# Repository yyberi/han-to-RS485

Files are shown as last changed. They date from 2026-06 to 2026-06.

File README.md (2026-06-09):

# Aidon HAN to RS485 Adapter

A small PCB that reads data from the Aidon electricity meter's HAN port and converts it to an RS485 bus, enabling integration with home automation systems, data loggers, and industrial equipment.

**PCB size:** 45 × 25 mm, 4-layer  
**Designed:** November 2022 by Yyberi

---

## Background

Aidon smart electricity meters (used by many Nordic utilities) expose a **HAN port** — a standard RJ12 connector that outputs UART serial data (DLMS/COSEM P1 telegrams) at 115200 baud. This board taps into that port and re-transmits the data over RS485, which is suited for longer cable runs and multi-drop topologies.

---

## How It Works

```
Aidon meter
  HAN port (RJ12)
       │
       ├─ +5V ──────────────────── powers the board
       └─ TX (UART 115200 baud) ── NPN buffer (Q1) ──► MAX13487E ──► RS485 (A/B)
```

1. The meter provides 5 V on the HAN port — no external power supply needed.
2. The UART TX line from the meter is buffered through an NPN transistor (Q1) that also handles the logic-level inversion.
3. The MAX13487EESA+T RS485 transceiver with automatic direction control retransmits the data on the RS485 bus.
4. TVS diode (D3) protects the RS485 lines against ESD and transients.
5. Two LEDs indicate power (D2) and data transmission activity (D1).

---

## Connectors

| Ref | Connector | Function |
|-----|---|---|
| J1  | RJ12 (DS1133-S60BPX) | HAN port — plugs into meter |
| J2  | 2-pin header 2.54 mm | Alternative/external power input (optional) |
| J3  | Phoenix Contact 3-pin 5.08 mm | RS485 output: A, B, GND |

### J1 — HAN Port Pinout (RJ12)

| Pin | Signal | Description |
|-----|---|---|
| 1 | +5V | Power from meter |
| 2 | – | Not connected |
| 3 | DATA | UART TX from meter (115200 8N1) |
| 4 | – | Not connected |
| 5 | GND | Ground |
| 6 | – | Not connected |

### J3 — RS485 Output

| Pin | Signal | Board silkscreen (top→bottom) |
|-----|---|---|
| 1 | GND | GND (bottom) |
| 2 | A (+)  | A (middle) |
| 3 | B (–)  | B (top) |

---

## Bill of Materials

| Ref | Value / Part | Package | LCSC # | Qty |
|-----|---|---|---|-----|
| IC1 | Maxim MAX13487EESA+T | SOIC-8 | C18347 | 1 |
| J1  | CONNFLY DS1133-S60BPX (RJ12) | Horizontal | C77859 | 1 |
| J2  | Molex 22284020 | 2×1 pin header 2.54 mm | C234182 | 1 |
| J3  | Phoenix Contact 1711738 | 3-pin 5.08 mm | C91156 | 1 |
| Q1  | MMS9013-H-TP (NPN) | SOT-23 | C90160 | 1 |
| D3  | ProTek PSM712-LF-T7 (TVS) | SOT-23 | C32677 | 1 |
| D1, D2 | NationStar NCD0805R1 (LED red) | 0805 | C84256 | 2 |
| R1, R3 | 510 Ω | 0805 | C17734 | 2 |
| R2  | 4.7 kΩ | 0805 | C17673 | 1 |
| R4  | 120 Ω (RS485 termination) | 0805 | C17437 | 1 |
| C1, C2 | 100 nF | 0805 | C49678 | 2 |

All LCSC part numbers are compatible with **JLCPCB SMT assembly**.

---

## Manufacturing

Gerber files, drill files, and pick-and-place position files are in the `AidonToRS485v2-gerbers/` folder.

### Ordering from JLCPCB

1. Zip the contents of `AidonToRS485v2-gerbers/`.
2. Upload to [jlcpcb.com](https://jlcpcb.com) and select **4 layers**.
3. For SMT assembly, upload the BOM (`BOM_AidonToRS485v2.xlsx`) and the position files (`*-top-pos.csv`).

**Recommended PCB stackup:** standard JLC04161H-7628 (or equivalent).

---

## Data Format

The Aidon meter outputs **DLMS/COSEM** P1 telegrams (similar to DSMR P1). Data is sent as UART at **115200 baud, 8N1** (8 data bits, no parity, 1 stop bit).

Library for parsing Aidon data:
- [aidon-comm](https://github.com/yyberi/aidon-comm) - HAN serial data to MQTT

---

## Getting Started

1. **Plug** the RJ12 cable into the meter's HAN port and the board's J1.
2. **Connect** your RS485 device or bus to J3 (A, B, GND).
3. **Power** is sourced directly from the meter. No external supply needed.
4. Configure your RS485 receiver for **115200 baud, 8N1**.
5. Data telegrams arrive automatically — the meter pushes data every 10 seconds (or as configured by the utility).

> **Note:** Some utilities require you to request HAN port activation from your grid operator before data is available.

---

## Repository Contents

```
AidonToRS485_v2/
├── AidonToRS485.kicad_pro       # KiCad project file
├── AidonToRS485.kicad_sch       # Schematic
├── AidonToRS485.kicad_pcb       # PCB layout
├── AidonToRS485.step            # 3D model (STEP)
├── BOM_AidonToRS485v2.xlsx      # Bill of materials (JLCPCB format)
├── BOM_AidonToRS485.csv         # Bill of materials (CSV)
└── AidonToRS485v2-gerbers/      # Gerber + drill + position files
```

---

## License

This hardware design is released under the **CERN Open Hardware Licence v2 – Permissive (CERN-OHL-P)**. You are free to use, modify, and manufacture this design, with or without attribution, and without requiring derivatives to be open source.

See [ohwr.org/cern_ohl_p_v2.txt](https://ohwr.org/cern_ohl_p_v2.txt) for the full license text.

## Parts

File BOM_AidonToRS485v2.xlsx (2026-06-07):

BOM_AidonToRS485
Comment | Designator | Footprint | LCSC Part Number | Quantity
120R | R4 | 0805 | C17437 | 1
510R | R3,R1 | 0805 | C17734 | 2
4K7 | R2 | 0805 | C17673 | 1
MMS9013-H-TP | Q1 | SOT-23 | C90160 | 1
Phoenix Contact 1711738 | J3 | Phoenix_MKDS-1.5-3-5.08_1x03_P5.08mm_Horizontal | C91156 | 1
MOLEX 22284020 | J2 | PinHeader_2x01_P2.54mm_Vertical | C234182 | 1
CONNFLY Elec DS1133-S60BPX | J1 | DS1133-S60BPX | C77859 | 1
Maxim Integrated MAX13487EESA+T | IC1 | SOIC-8_150mil | C18347 | 1
ProTek Devices PSM712-LF-T7 | D3 | SOT-23(SOT-23-3) | C32677 | 1
Foshan NationStar Optoelectronics NCD0805R1 | D2 | 0805 | C84256 | 1
Foshan NationStar Optoelectronics NCD0805R1 | D1 | 0805 | C84256 | 1
100nF | C2,C1 | 0805 | C49678 | 2

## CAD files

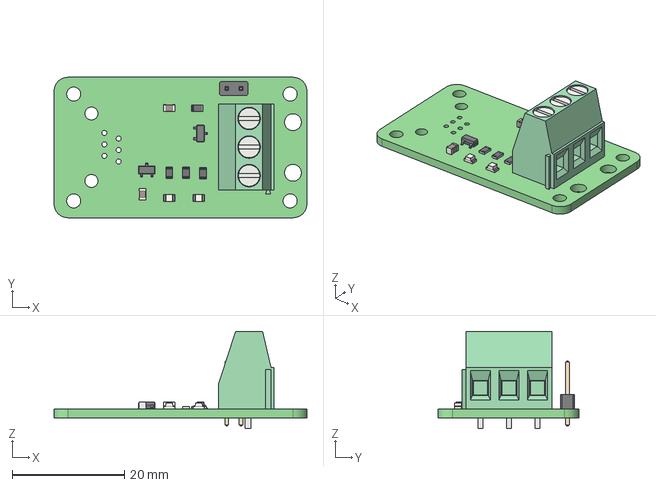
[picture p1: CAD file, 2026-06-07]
AidonToRS485.step
45.0 x 25.0 x 17.3 mm
AidonToRS485 PCB

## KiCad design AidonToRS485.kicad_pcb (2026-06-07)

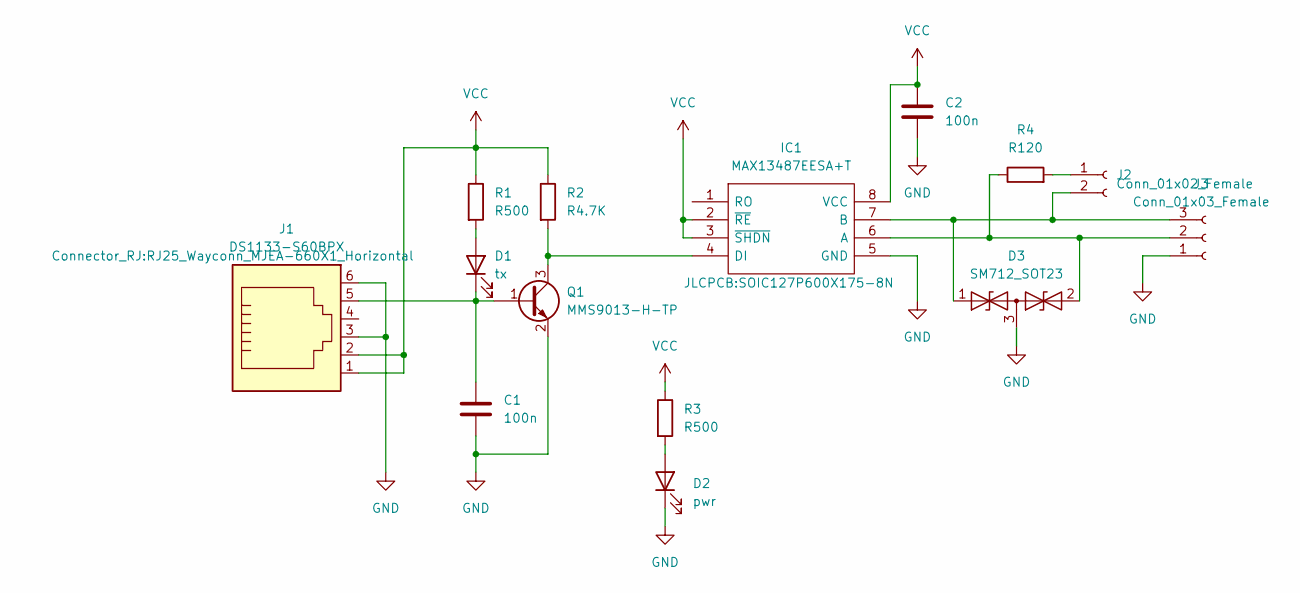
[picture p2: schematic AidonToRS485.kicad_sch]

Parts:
C1, C2: 100n; C_0805_2012Metric
D1: tx; LED_0805_2012Metric; JLCPCB Part # C84256
D2: pwr; LED_0805_2012Metric; JLCPCB Part # C84256
D3: SM712_SOT23; SOT-23; JLCPCB Part # C404012
IC1: MAX13487EESA+T; SOIC127P600X175-8N; Manufacturer_Part_Number MAX13487EESA+T; Mouser Part Number 700-MAX13487EESAT
J1: DS1133-S60BPX; RJ25_Wayconn_MJEA-660X1_Horizontal; JLCPCB Part # C77859
J2: Conn_01x02_Female; PinHeader_2x01_P2.54mm_Vertical; JLCPCB Part # C234182
J3: Conn_01x03_Female; TerminalBlock_Phoenix_MKDS-1,5-3-5.08_1x03_P5.08mm_Horizont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; JLCPCB Part # C91156
Q1: MMS9013-H-TP; SOT-23; JLCPCB Part # C90160
R1, R3: R500; R_0805_2012Metric
R2: R4.7K; R_0805_2012Metric
R4: R120; R_0805_2012Metric

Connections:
GND: C1.2, C2.2, D2.1 (K), D3.3 (common), IC1.5 (GND), J1.3, J1.6, J3.1, Q1.2 (E)
unnamed: C1.1, D1.1 (K), J1.5, Q1.1 (B)
unnamed: D1.2 (A), R1.2
unnamed: D2.2 (A), R3.2
unnamed: D3.1 (A1), IC1.7 (B), J2.2, J3.3
unnamed: D3.2 (A2), IC1.6 (A), J3.2, R4.1
unnamed: IC1.4 (DI), Q1.3 (C), R2.2
unnamed: J2.1, R4.2
VCC: C2.1, IC1.2 (~RE), IC1.3 (~SHDN), IC1.8 (VCC), J1.1, J1.2, R1.1, R2.1, R3.1

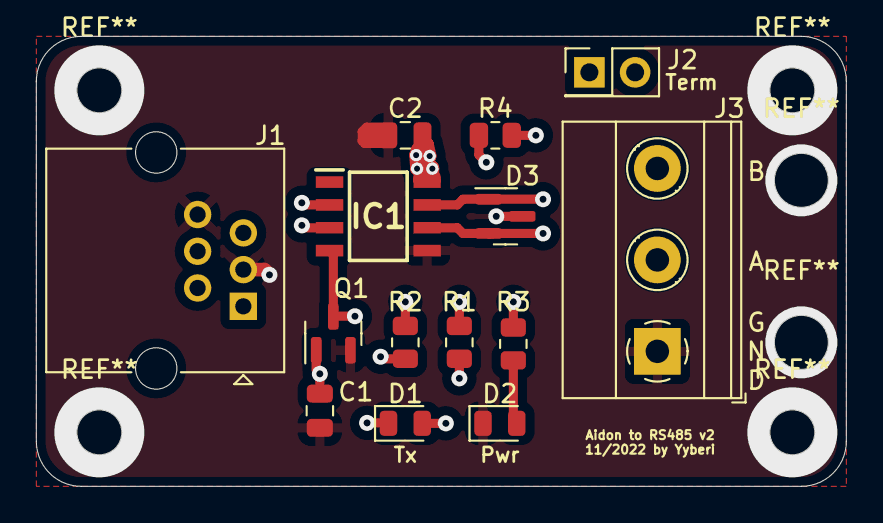
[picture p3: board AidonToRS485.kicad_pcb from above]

Board: 4 copper layers, 45.0 x 25.0 mm, 14 parts (0 on the bottom side), 9 nets.
